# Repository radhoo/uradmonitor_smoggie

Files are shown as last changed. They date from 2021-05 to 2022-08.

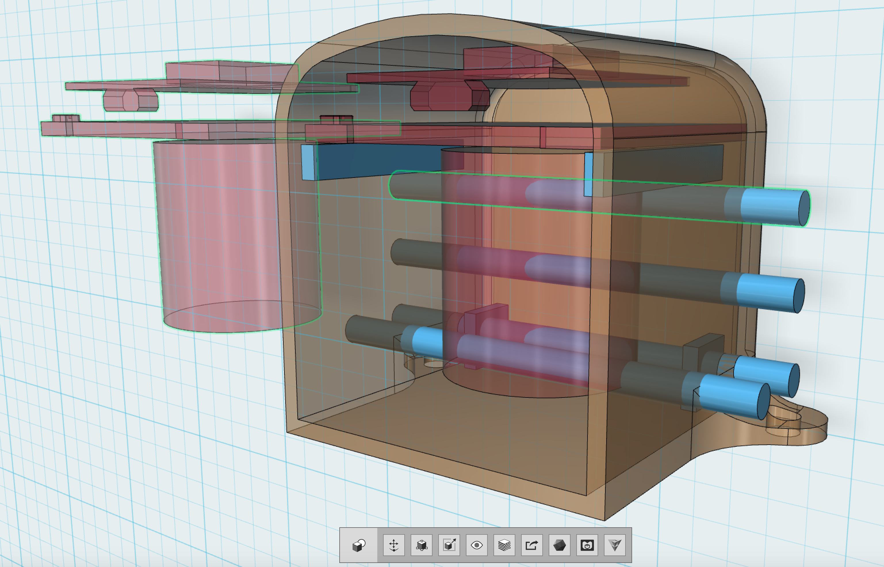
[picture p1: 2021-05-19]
pics/Screenshot 2020-02-19 at 22.15.20.png

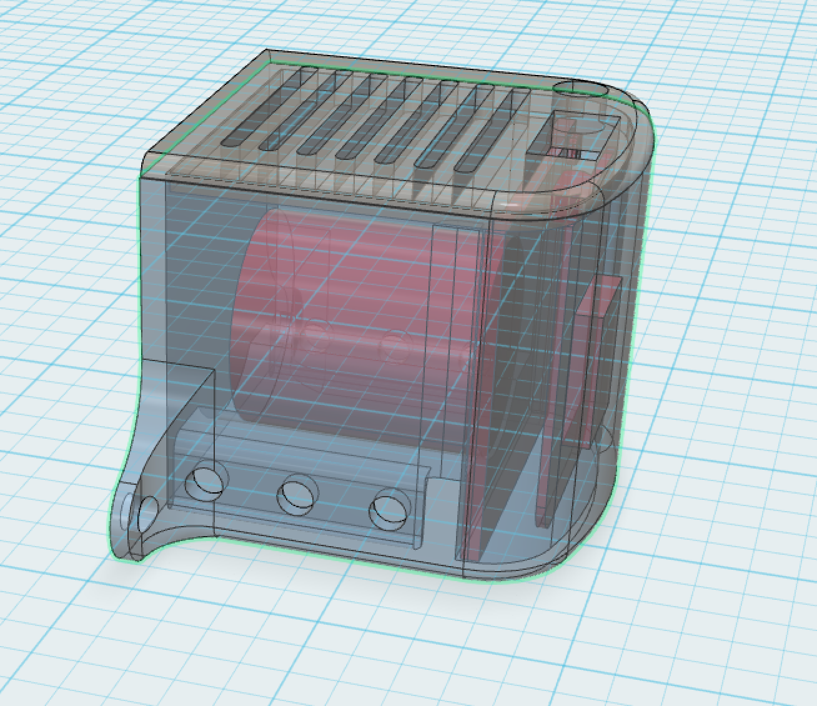
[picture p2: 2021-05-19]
pics/Screenshot 2020-02-19 at 23.36.54.png

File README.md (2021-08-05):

# uradmonitor_smoggie
SMOGGIE is an ultra-low cost automated air quality monitor with a rain proof enclosure and a simple mount system to make installation easy. 

This repo includes all the blueprints needed to build Smoggie:
1) PCB shield for Wemos D1 Wifi module , plus a series of sensors: 
Particulate Matter: Plantower PMSA003, PMS5003, PMS6003, PMS7003, Winsen ZH03A, Cubic PM2009
CO2: Winsen MH-Z19B, Cubic CM1106, Mixsen 6010 NDIR CO2 sensors
Gas: Winsen ZE03
2) Code, Arduino compatible, including local webserver, HTTP Client and all the drivers for the sensors supported
3) 3d Printable enclosure (Either Filament/FDM or Resin/SLA)



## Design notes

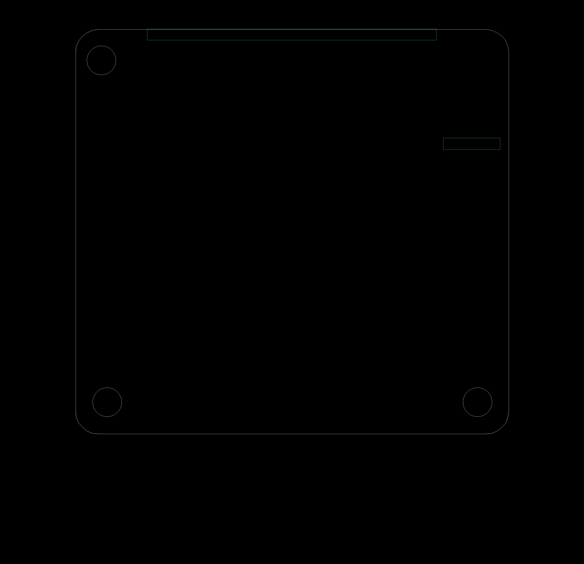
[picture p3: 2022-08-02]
pcb/005/pics/milling_v5.png

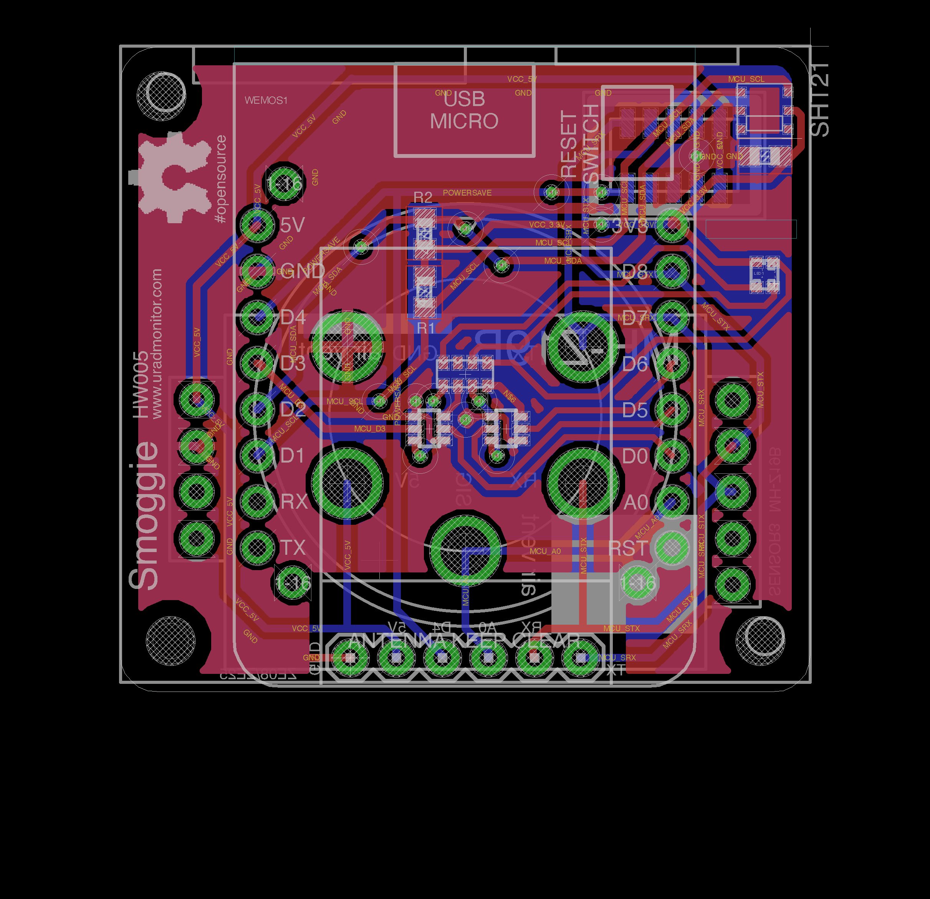
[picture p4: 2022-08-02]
pcb/005/pics/pcb_v5.png

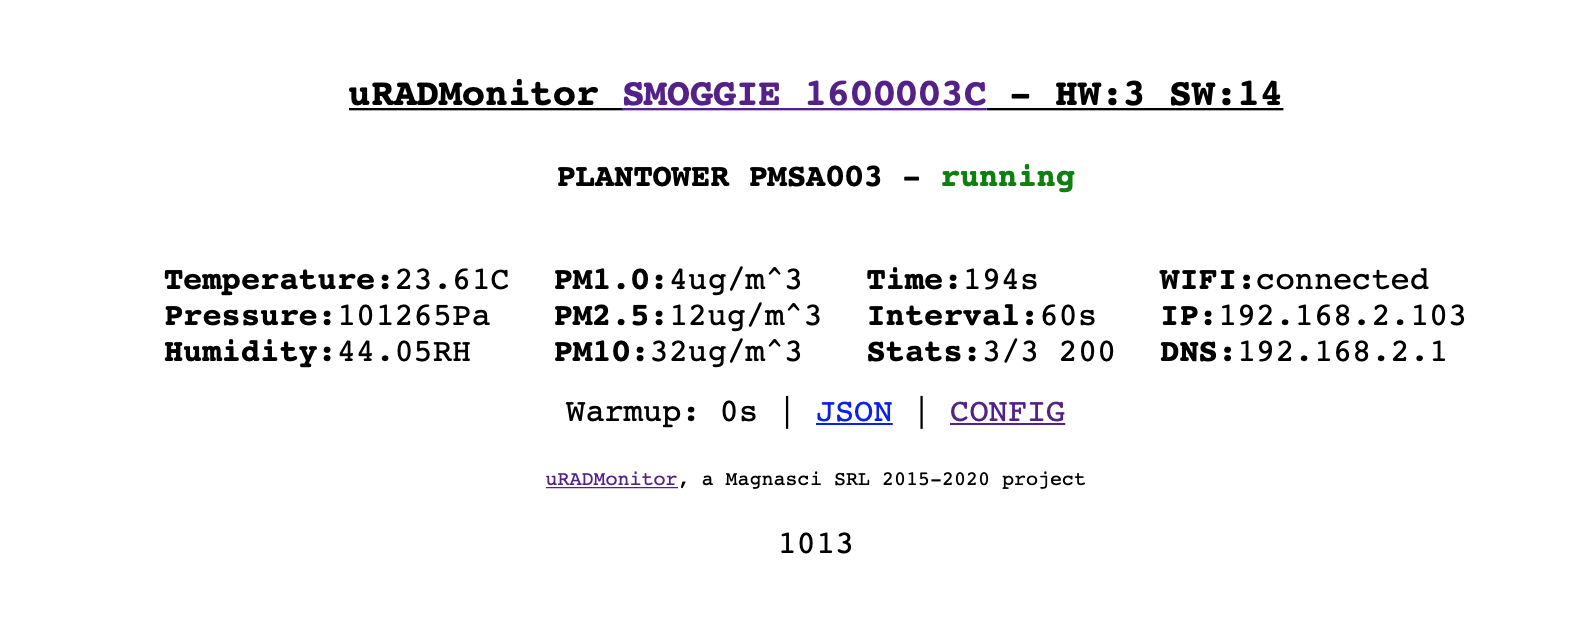
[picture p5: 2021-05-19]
pics/Screenshot 2020-02-21 at 13.33.23.png

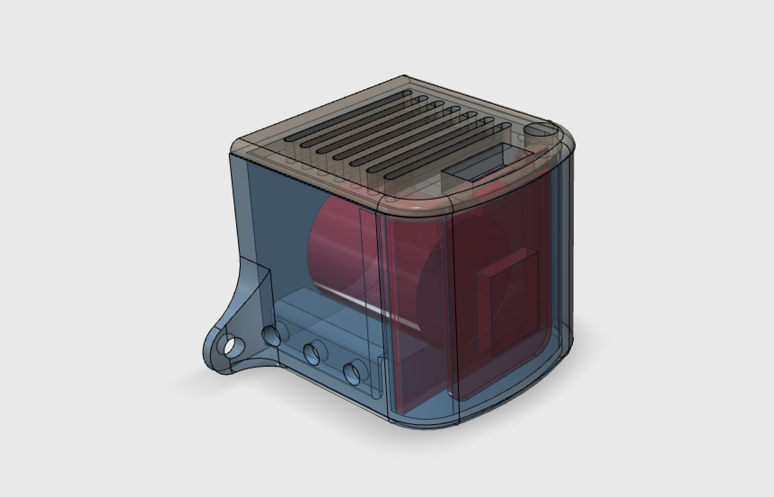
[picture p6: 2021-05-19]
pics/Screenshot 2020-02-19 at 23.38.52.png

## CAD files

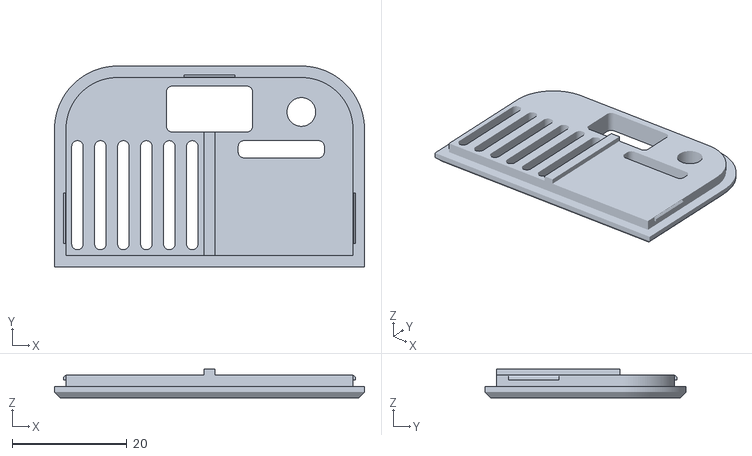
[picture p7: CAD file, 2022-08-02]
enclosure/SMOGGIE_LID_PMS5003.stl
54.0 x 35.0 x 5.00

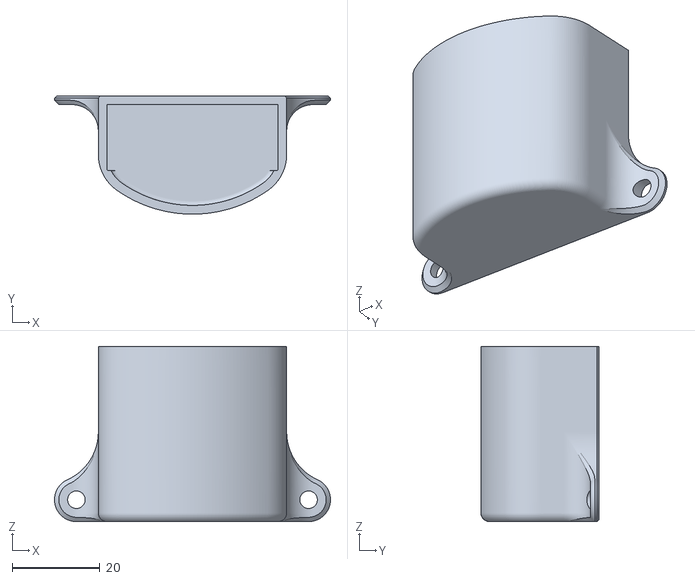
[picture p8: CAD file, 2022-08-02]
enclosure/SMOGGIE_PMSA003_BODY_V3_FDM_LOGO.stl
63.0 x 27.0 x 40.0

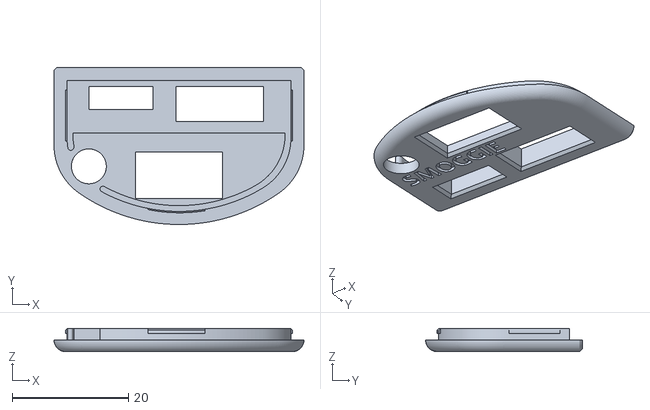
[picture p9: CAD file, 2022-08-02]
enclosure/SMOGGIE_LID_SMALL_V5_RESIN.stl
43.0 x 27.0 x 4.00

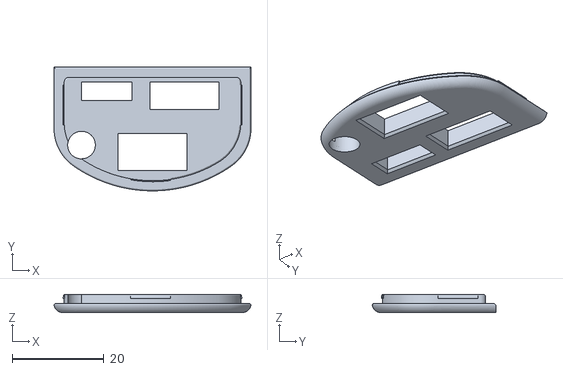
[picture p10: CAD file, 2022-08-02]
enclosure/SMOGGIE_LID_SMALL_V6_FDM_NOLOGO.stl
43.0 x 27.0 x 4.00

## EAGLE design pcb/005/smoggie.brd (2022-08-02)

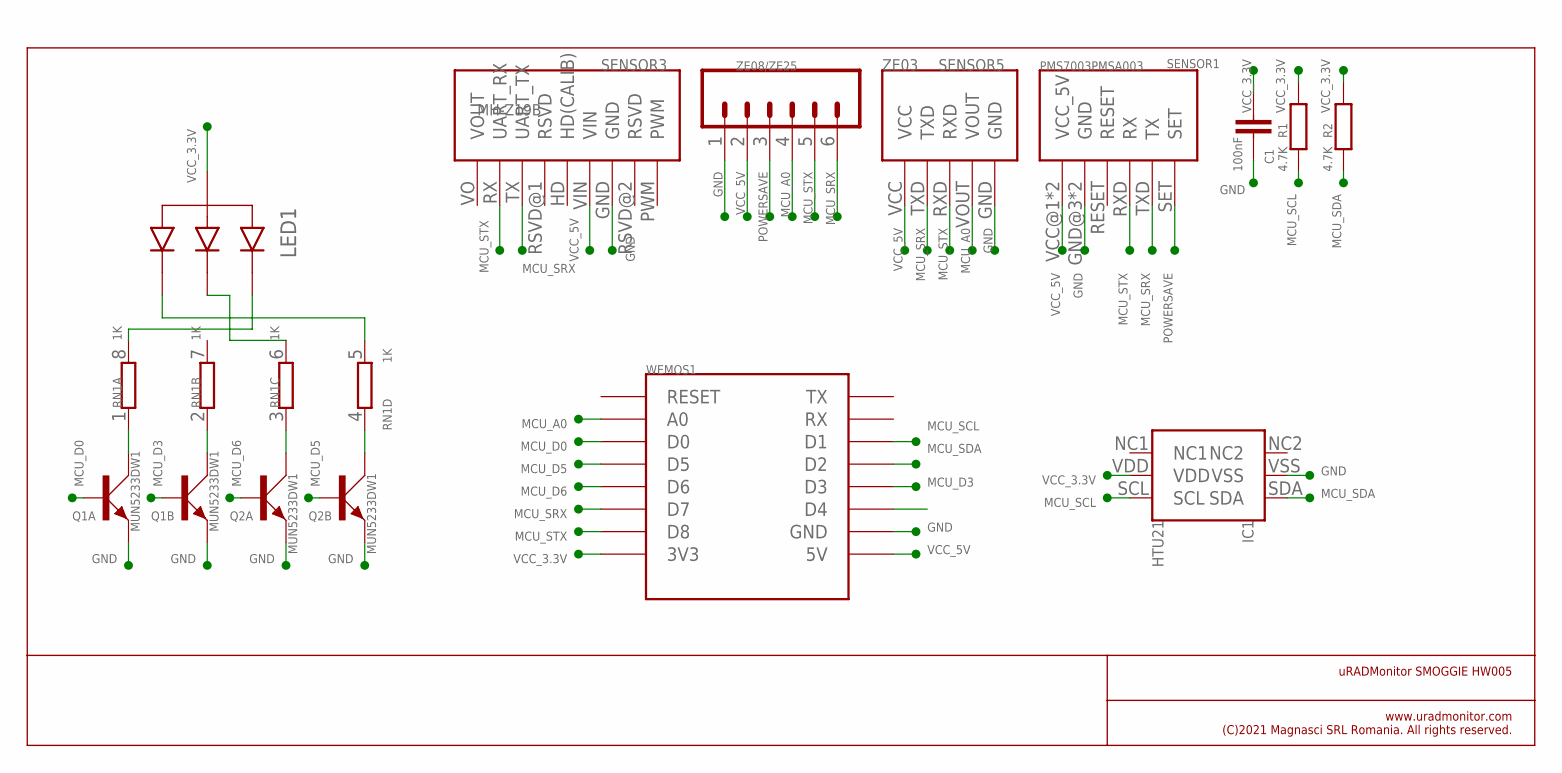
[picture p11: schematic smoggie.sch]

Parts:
C1: 100nF; C0603
IC1: HTU21; SHT21
LED1: LED_1615_RGB_CA; 1615_LED_CA
Q1, Q2: MUN5233DW1; SOT363_PHILIPS
R1, R2: 4.7K; R0603
RN1: 1K; 0603-ARC
SENSOR1: PMS7003PMSA003; PMSA003
SENSOR3: MH-Z19B
SENSOR5: ZE03
WEMOS1: 11; WEMOS-D1-MINI
ZE08/ZE25: M06SIP; 1X06

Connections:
GND: C1.1, IC1.VSS, Q1.1 (E), Q1.4 (E), Q2.1 (E), Q2.4 (E), SENSOR1.GND@3 (GND), SENSOR1.GND@4 (GND), SENSOR3.GND, SENSOR5.GND, WEMOS1.GND, ZE08/ZE25.1
MCU_A0: SENSOR5.VOUT, WEMOS1.A0, ZE08/ZE25.4
MCU_D0: Q1.2 (B), WEMOS1.D0
MCU_D3: Q1.5 (B), WEMOS1.D3
MCU_D5: Q2.5 (B), WEMOS1.D5
MCU_D6: Q2.2 (B), WEMOS1.D6
MCU_SCL: IC1.SCL, R1.2, WEMOS1.D1
MCU_SDA: IC1.SDA, R2.2, WEMOS1.D2
MCU_SRX: SENSOR1.TXD (TX), SENSOR3.TX (UART_TX), SENSOR5.TXD, WEMOS1.D7, ZE08/ZE25.6
MCU_STX: SENSOR1.RXD (RX), SENSOR3.RX (UART_RX), SENSOR5.RXD, WEMOS1.D8, ZE08/ZE25.5
unnamed: LED1.P$4 (P4_BLUE), RN1.8 (2)
unnamed: LED1.P$3 (P3_GREEN), RN1.6 (2)
unnamed: Q1.6 (C), RN1.1
unnamed: Q1.3 (C), RN1.2 (1)
unnamed: Q2.6 (C), RN1.3 (1)
unnamed: Q2.3 (C), RN1.4 (1)
unnamed: LED1.P$2 (P2_RED), RN1.5 (2)
POWERSAVE: SENSOR1.SET, ZE08/ZE25.3
VCC_3.3V: C1.2, IC1.VDD, LED1.P$1 (P1_CA), R1.1, R2.1, WEMOS1.3V3
VCC_5V: SENSOR1.VCC@1 (VCC_5V), SENSOR1.VCC@2 (VCC_5V), SENSOR3.VIN, SENSOR5.VCC, WEMOS1.5V, ZE08/ZE25.2

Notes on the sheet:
uRADMonitor SMOGGIE HW005
www.uradmonitor.com (C)2021 Magnasci SRL Romania. All rights reserved.

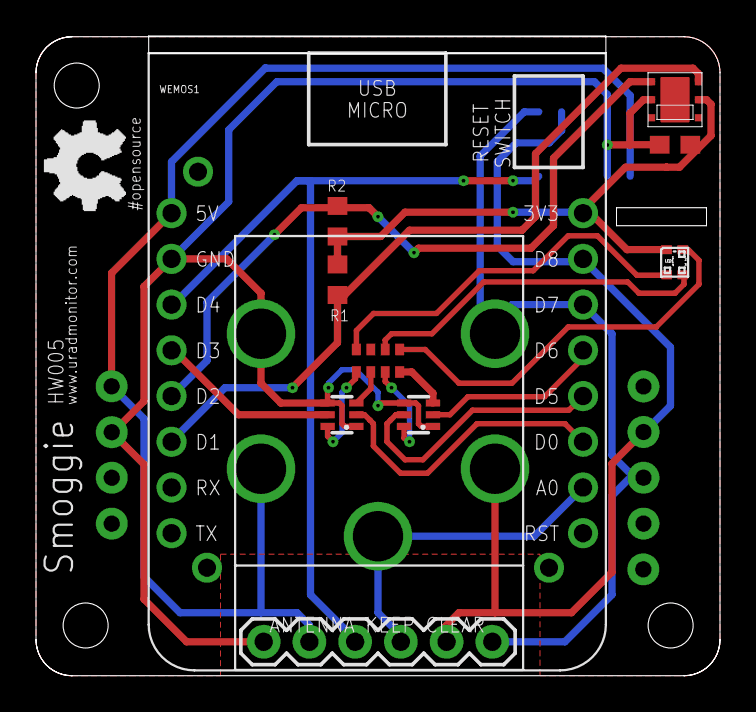
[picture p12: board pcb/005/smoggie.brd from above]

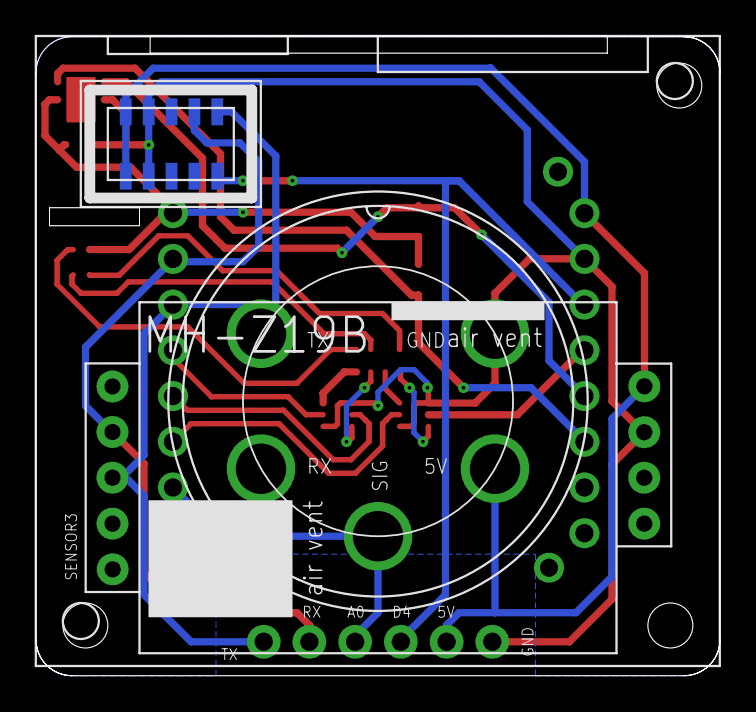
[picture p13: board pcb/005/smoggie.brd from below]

Board: 2 copper layers, 38.0 x 35.5 mm, 13 parts (3 on the bottom side), 20 nets.

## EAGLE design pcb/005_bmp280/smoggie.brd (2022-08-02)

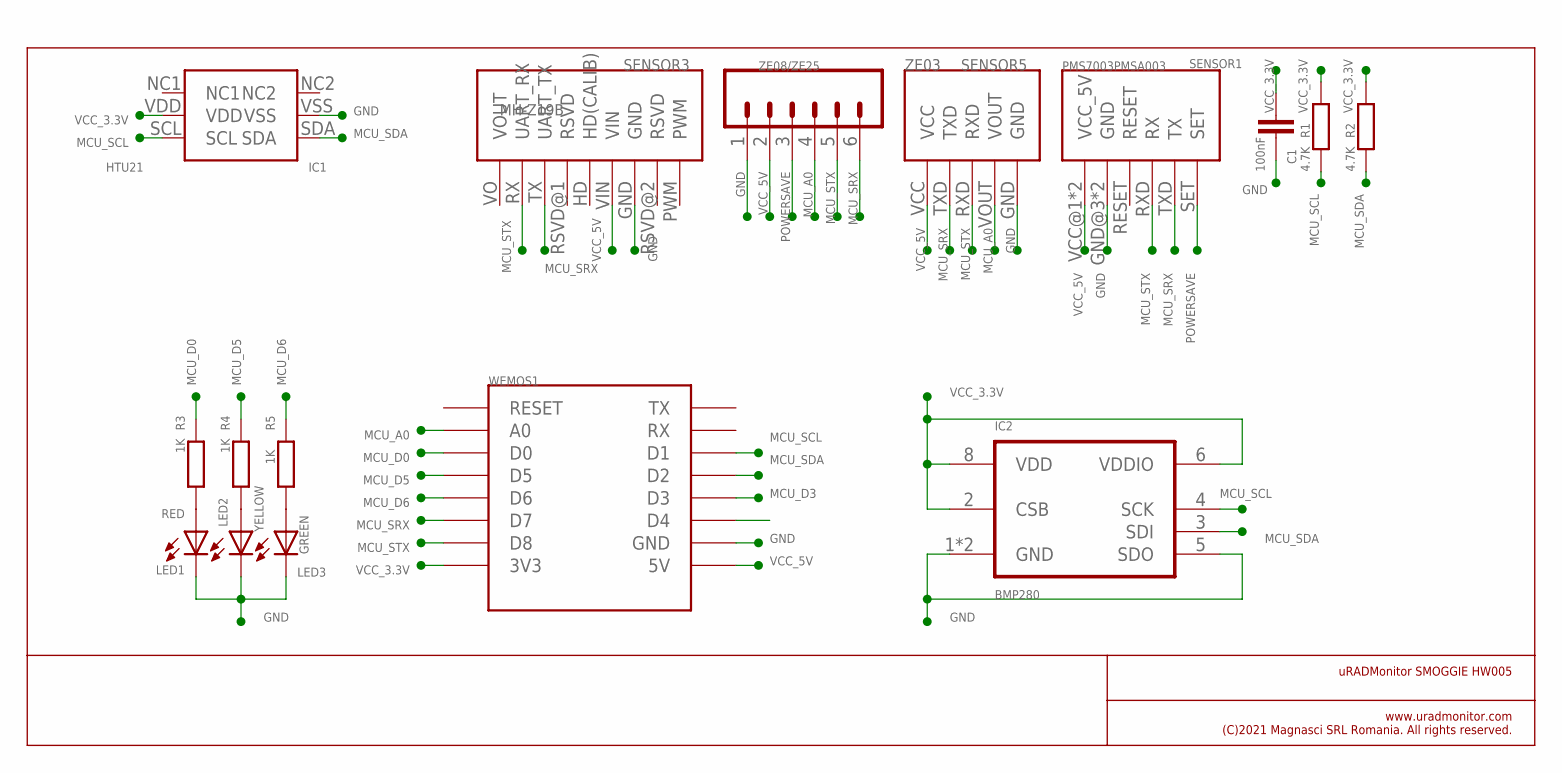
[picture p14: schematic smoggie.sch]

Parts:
C1: 100nF; C0603
IC1: HTU21; SHT21
IC2: BMP280
LED1: RED; SML0603
LED2: YELLOW; SML0603
LED3: GREEN; SML0603
R1, R2: 4.7K; R0603
R3, R4, R5: 1K; R0603
SENSOR1: PMS7003PMSA003; PMSA003
SENSOR3: MH-Z19B
SENSOR5: ZE03
WEMOS1: 11; WEMOS-D1-MINI
ZE08/ZE25: M06SIP; 1X06

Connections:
GND: C1.1, IC1.VSS, IC2.1 (GND), IC2.5 (SDO), IC2.7 (GND), LED1.C, LED2.C, LED3.C, SENSOR1.GND@3 (GND), SENSOR1.GND@4 (GND), SENSOR3.GND, SENSOR5.GND, WEMOS1.GND, ZE08/ZE25.1
MCU_A0: SENSOR5.VOUT, WEMOS1.A0, ZE08/ZE25.4
MCU_D0: R3.1, WEMOS1.D0
MCU_D3: WEMOS1.D3
MCU_D5: R4.1, WEMOS1.D5
MCU_D6: R5.1, WEMOS1.D6
MCU_SCL: IC1.SCL, IC2.4 (SCK), R1.2, WEMOS1.D1
MCU_SDA: IC1.SDA, IC2.3 (SDI), R2.2, WEMOS1.D2
MCU_SRX: SENSOR1.TXD (TX), SENSOR3.TX (UART_TX), SENSOR5.TXD, WEMOS1.D7, ZE08/ZE25.6
MCU_STX: SENSOR1.RXD (RX), SENSOR3.RX (UART_RX), SENSOR5.RXD, WEMOS1.D8, ZE08/ZE25.5
unnamed: LED2.A, R4.2
unnamed: LED3.A, R5.2
unnamed: LED1.A, R3.2
POWERSAVE: SENSOR1.SET, ZE08/ZE25.3
VCC_3.3V: C1.2, IC1.VDD, IC2.2 (CSB), IC2.6 (VDDIO), IC2.8 (VDD), R1.1, R2.1, WEMOS1.3V3
VCC_5V: SENSOR1.VCC@1 (VCC_5V), SENSOR1.VCC@2 (VCC_5V), SENSOR3.VIN, SENSOR5.VCC, WEMOS1.5V, ZE08/ZE25.2

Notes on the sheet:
uRADMonitor SMOGGIE HW005
www.uradmonitor.com (C)2021 Magnasci SRL Romania. All rights reserved.

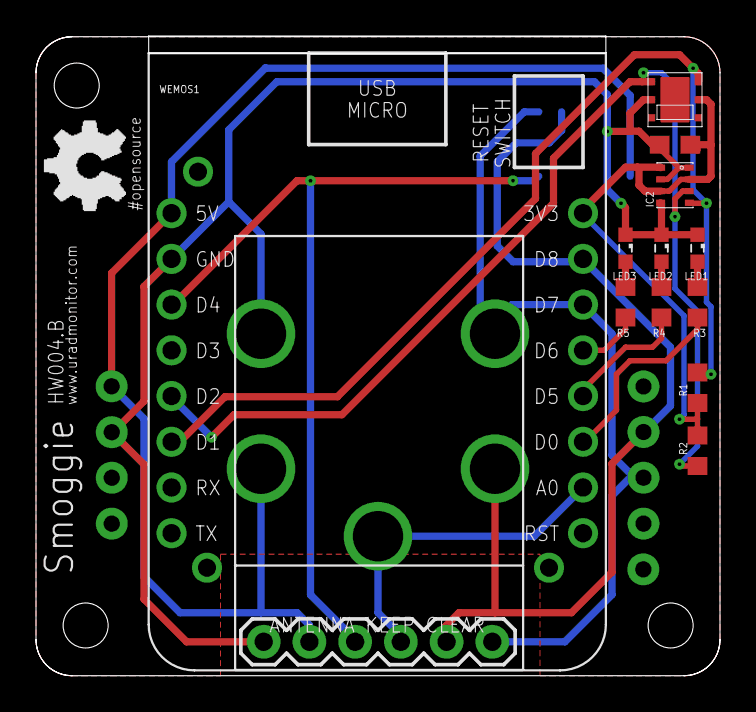
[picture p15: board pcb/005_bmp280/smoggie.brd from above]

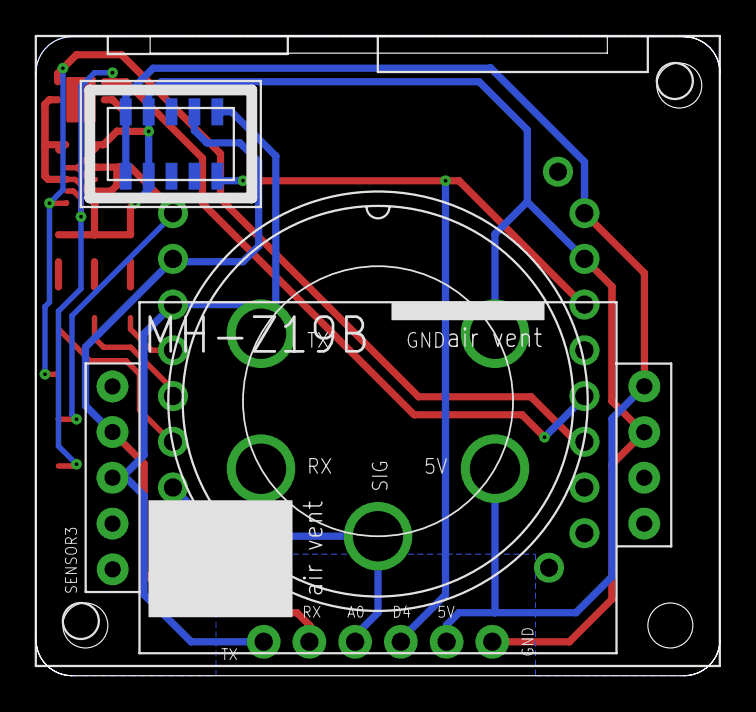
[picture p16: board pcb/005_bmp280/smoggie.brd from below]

Board: 2 copper layers, 38.0 x 35.5 mm, 16 parts (3 on the bottom side), 15 nets.

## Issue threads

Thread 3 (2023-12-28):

Unclear license status for project

jburkal, 2023-12-28:
In commit 6bc1a1a, the project changed from a Creative Commons license to GPL-3.0, as seen in its `LICENSE.md` file:
https://github.com/radhoo/uradmonitor_smoggie/blob/6bc1a1a188206171720ba76ae22d7a8314056fc2/LICENSE.md#L1-L2

However, in commit 51c5c496 several files changed license to a proprietary one.
For example, `calibration.cpp` changed from:
https://github.com/radhoo/uradmonitor_smoggie/blob/6bc1a1a188206171720ba76ae22d7a8314056fc2/code/smoggie/calibration.cpp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

to:
https://github.com/radhoo/uradmonitor_smoggie/blob/51c5c496bd08a835604b386b398806e214ef0fb8/code/smoggie/calibration.cpp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

This is the case for the following files:
 - `code/smoggie/calibration.cpp`
 - `code/smoggie/calibration.h`
 - `code/smoggie/src/data/data_ex.cpp`
 - `code/smoggie/src/data/data_ex.h`
 - `code/smoggie/src/drivers/drv_pms_generic.cpp`
 - `code/smoggie/src/drivers/drv_pms_generic.h`

If this was an intentional change then the `LICENSE.md` file should be updated to a more appropriate license. If it was just a mistake, then it would be nice to have the affected files updated to the GPL-3.0 license.

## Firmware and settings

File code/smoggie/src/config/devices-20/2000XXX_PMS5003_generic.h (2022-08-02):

#pragma once

#include "../sensors.h"


#define 			ENCRYPT_PAYLOAD										// Payload should always be encrypted, E3/E3B format
#define 			DEFAULT_SEND_INTERVAL 		60	 					// 5min for LoraWAN
#define 			DEFAULT_WARMUP		 		10	 					// 110sec for CO2
#define 			VER_HW						5
#define				DEV_CLASS					0x20
#define				DEFAULT_SERVER 				"data.uradmonitor.com"	// The name of the virtual host which you want to  contact to - hostname
#define 			DEFAULT_SCRIPT 				"/api/v1/upload/ex"	// server resource to call
#define 			DEFAULT_INTERNET_SSID		"WRM_2.4GHz"			// default WIFI to connect to
#define 			DEFAULT_INTERNET_KEY		"qq_wifi_4929"			// default WIFI key
#define 			DEFAULT_MUTE				1

#define       		DEFAULT_DISABLEAP     		0         // 0 if not used, or number of seconds to disable internal hotspot
#define 			DEFAULT_ENCRYPT				1
#define 			USE_SHT

#define 			SENSOR 						SENSOR_PMS5003
#define 			SENSOR_BAUDRATE				9600


//#define DEBUG

#include "../../data/data_ex.h"

// drivers
#ifdef USE_SHT
	#include "../../drivers/drv_sht21.h"
#else
	#include "../../drivers/drv_bme280.h"
#endif

#include "../../drivers/drv_pms_generic.h"

#define SENSOR_CLASS PMS
#define SENSOR_NAME "PLANTOWER PMS5003"
#define DATA_CLASS	 Data_EX
#define FACTOR 0.63
#define INCREASE_LIFESPAN // cannot use IL on PMSA003 Plantower sensors

/*
// normal enclosure
#define				CAL_DEF_TEMPERATURE			0x00648384		// -9 // new
#define				CAL_DEF_PRESSURE			0x00640000		// 1*x + 0
#define				CAL_DEF_HUMIDITY			0x00640BB8		// +30 //new
#define				CAL_DEF_VOC					0x00640000		// 1*x + 0
#define				CAL_DEF_CO2					0x00640000		// 1*x + 0
#define				CAL_DEF_CH2O				0x00640000		// 1*x + 0
#define				CAL_DEF_PM25				0x00640000		// 1*x + 0
#define				CAL_DEF_NOISE				0x00640000		// 1*x + 0
#define				CAL_DEF_PM1					0x00640000		// 1*x + 0
#define				CAL_DEF_PM10				0x00640000		// 1*x + 0
#define				CAL_DEF_O3					0x00640000		// 1*x + 0
#define				CAL_DEF_ZE03S1				0x00640000		// 1*x + 0
#define				CAL_DEF_ZE03S2				0x00640000		// 1*x + 0
#define				CAL_DEF_ZE03S3				0x00640000		// 1*x + 0
#define				CAL_DEF_ZE03S4				0x00640000		// 1*x + 0
*/
// stevenson enclosure
#define				CAL_DEF_TEMPERATURE			0x00648366		// -8.7
#define				CAL_DEF_PRESSURE			0x00640000		// 1*x + 0
#define				CAL_DEF_HUMIDITY			0x006409C4		// +25
#define				CAL_DEF_VOC					0x00640000		// 1*x + 0
#define				CAL_DEF_CO2					0x00640000		// 1*x + 0
#define				CAL_DEF_CH2O				0x00640000		// 1*x + 0
#define				CAL_DEF_PM25				0x00640000		// 1*x + 0
#define				CAL_DEF_NOISE				0x00640000		// 1*x + 0
#define				CAL_DEF_PM1					0x00640000		// 1*x + 0
#define				CAL_DEF_PM10				0x00640000		// 1*x + 0
#define				CAL_DEF_O3					0x00640000		// 1*x + 0
#define				CAL_DEF_ZE03S1				0x00640000		// 1*x + 0
#define				CAL_DEF_ZE03S2				0x00640000		// 1*x + 0
#define				CAL_DEF_ZE03S3				0x00640000		// 1*x + 0
#define				CAL_DEF_ZE03S4				0x00640000		// 1*x + 0

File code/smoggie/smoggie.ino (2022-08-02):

/* Create a WiFi access point and provide a web server on it. */
// FW006 - current
#include "uradmonitor.h"
#include "webserver.h"
#include "data_client.h"

uradmonitor       urad;
Webserver         web;
DataClient        client;

char buffer[BUFFER_SIZE];

void sendFunc() {
  client.sendData();
}

void setup() {
  Serial.begin(9600);
  
  urad.init(buffer, BUFFER_SIZE, &sendFunc);
  // configure globals
#if DEV_CLASS == SMOGGIE_PM_KIT
  byte mac[6];  
  WiFi.macAddress(mac);
  urad.setDeviceID(((uint32_t)DEV_CLASS << 24) | ((uint32_t)mac[3] << 16) | ((uint32_t)mac[4] << 8) | ((uint32_t)mac[5]));
  #ifdef DEBUG
    Serial.printf("Device ID: %08lX\n", urad.getDeviceID());
  #endif  
#else
  urad.setDeviceID(((uint32_t)DEV_CLASS << 24) | ((uint32_t)DEFAULT_DEV_NUMBER & 0x00FFFFFF));
#endif
  // goes before initnetwork
  urad.loadSettings();
  
  // init sensors
  urad.initSensors();

  urad.initNetwork();  

  
  // init webserver
  web.init(&urad, buffer, BUFFER_SIZE);

  // init client
  client.init(&urad, buffer, BUFFER_SIZE);
 
}



void loop() {
  urad.loop() ;
  web.loop(); 
}

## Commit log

2021-05-19 first release
    [n2_pmsa003_lid.stl, pms5003_lid_2.stl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]
2022-08-02 hardware v5 smoggie-kit
    [SMOGGIE_LID_PMS5003.stl, SMOGGIE_LID_SMALL_V5_RESIN.stl, SMOGGIE_LID_SMALL_V6_FDM_NOLOGO.stl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]

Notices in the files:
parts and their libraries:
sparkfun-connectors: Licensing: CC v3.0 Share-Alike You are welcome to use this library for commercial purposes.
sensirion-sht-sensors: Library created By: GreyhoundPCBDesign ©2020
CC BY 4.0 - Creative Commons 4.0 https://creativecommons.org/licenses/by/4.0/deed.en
